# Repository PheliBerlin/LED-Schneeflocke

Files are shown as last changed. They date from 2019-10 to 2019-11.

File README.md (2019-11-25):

# LED-Schneeflocke

Eine leuchtende LED Schneeflocke für den Schreibtisch

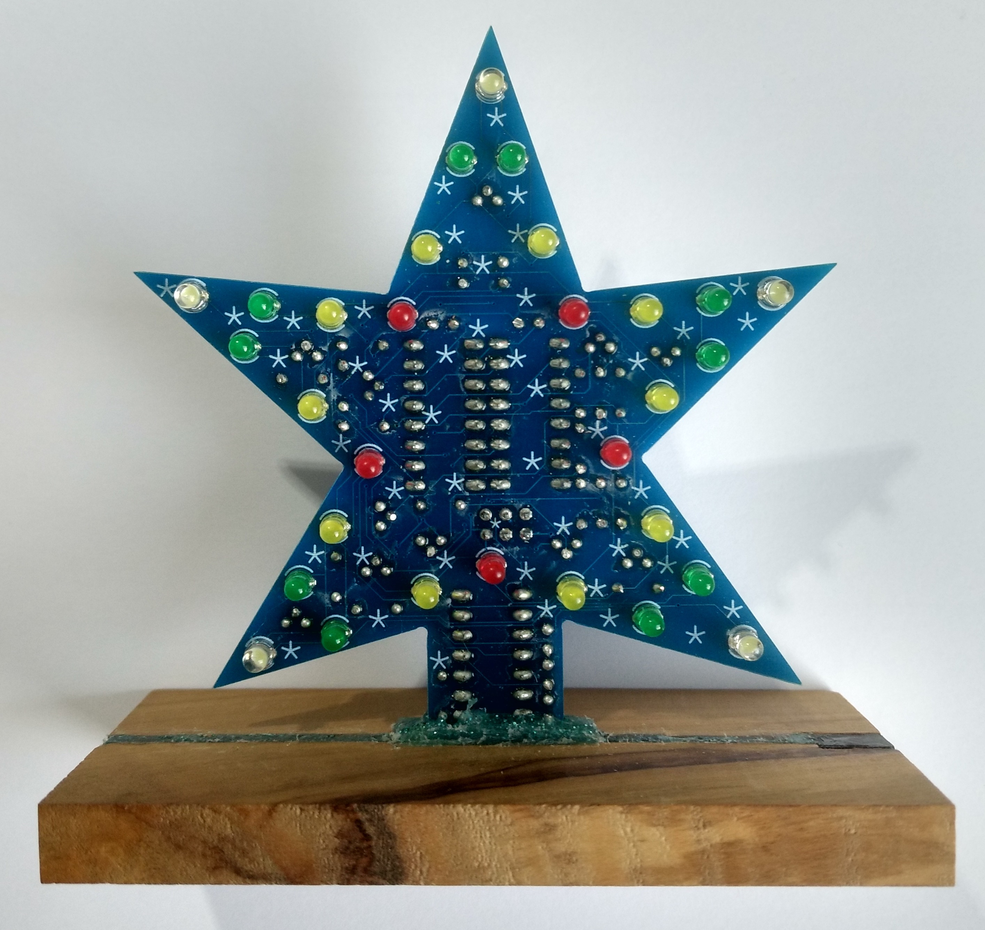
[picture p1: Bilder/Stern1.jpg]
Aufgebaut


Gesteuert wird alles mit einen ATtiny84, der mit zwei Shiftregistern die 30 LED schaltet.

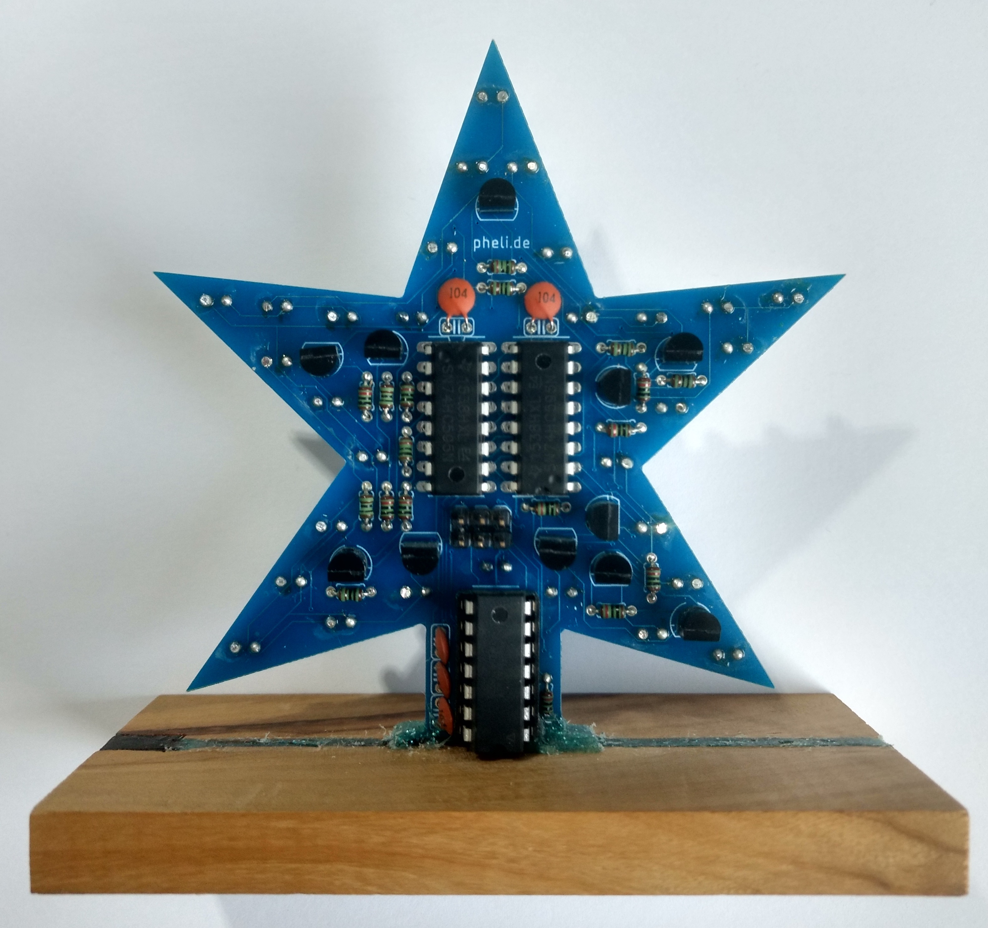
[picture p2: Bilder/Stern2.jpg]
ATtiny


Als Fuß habe ich ein Stück Holz vom Olivenbaum genommen.

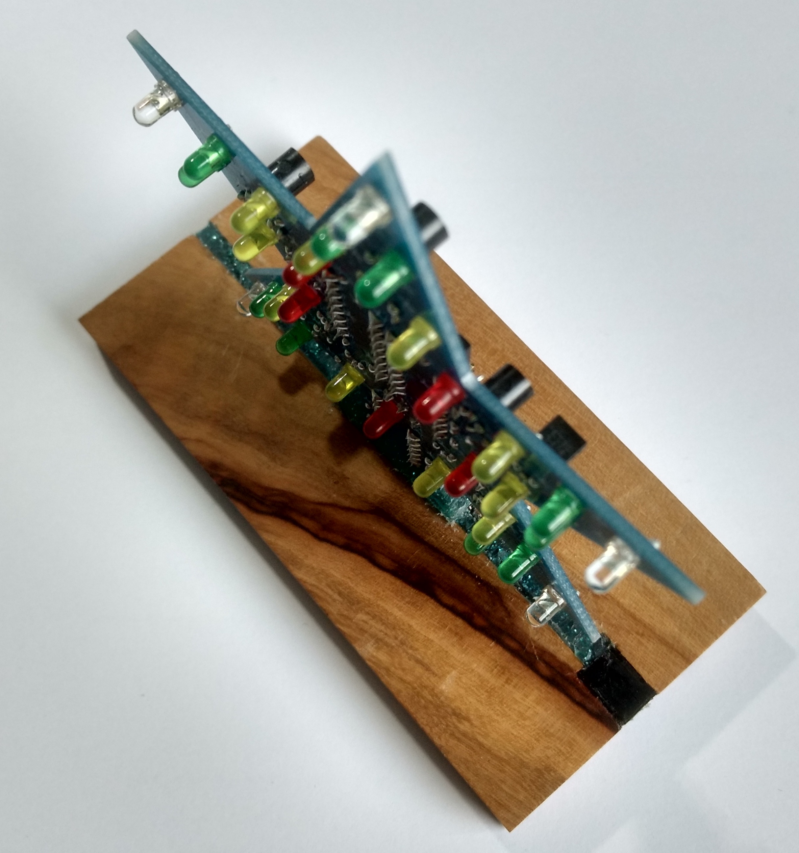
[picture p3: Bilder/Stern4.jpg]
Standfuß


Da es zum Anschluß an den USB- Anschluß gedacht war, sollte es auch nicht zu viel Strom ziehen. Obwohl ich auf keine Optimierungen im Stromverbrauch geachtet habe, ist der Stromverbrauch auch bei allen 30 leuchtenden LED nur gering.

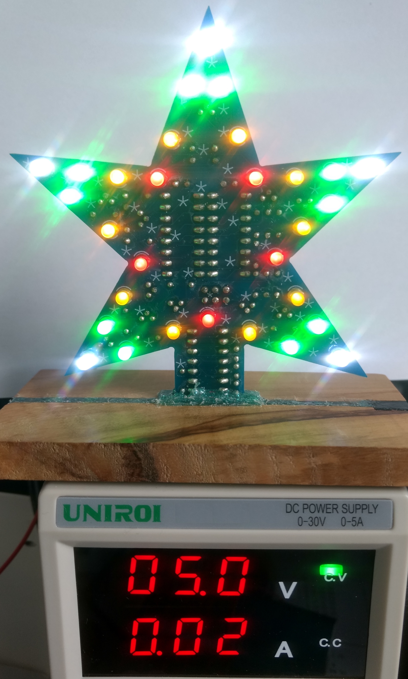
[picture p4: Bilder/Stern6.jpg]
Strom


Die Veröffentlichung erfolgt hier unter GNU General Public License Version 3.

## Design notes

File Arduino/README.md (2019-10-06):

xmasStern - Der Weihnachtsstern
==========

Installation
-------
Einfach den Ordner xmasStern in den Arduino library Ordner kopieren.

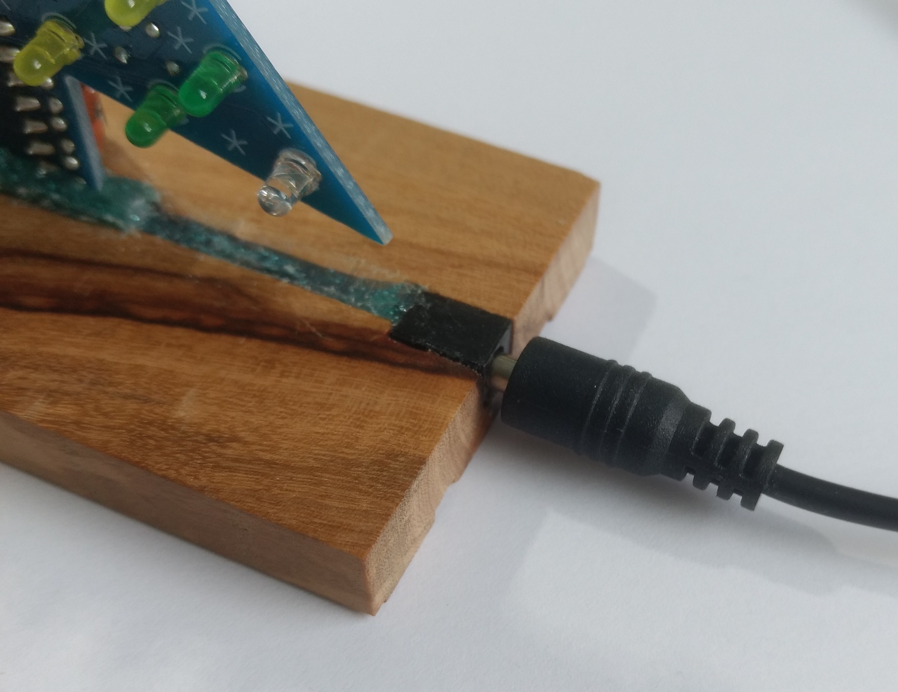
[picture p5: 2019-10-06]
Bilder/Stern5.jpg

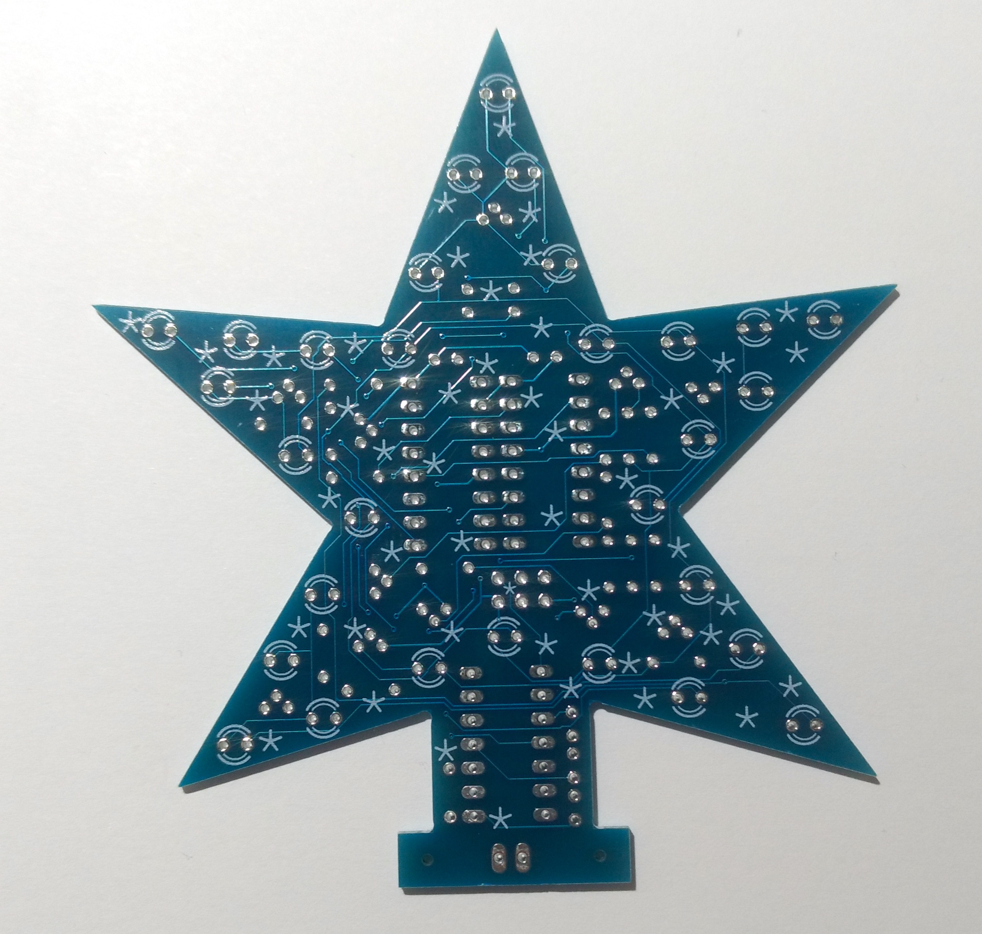
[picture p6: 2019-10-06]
Bilder/Stern3.jpg

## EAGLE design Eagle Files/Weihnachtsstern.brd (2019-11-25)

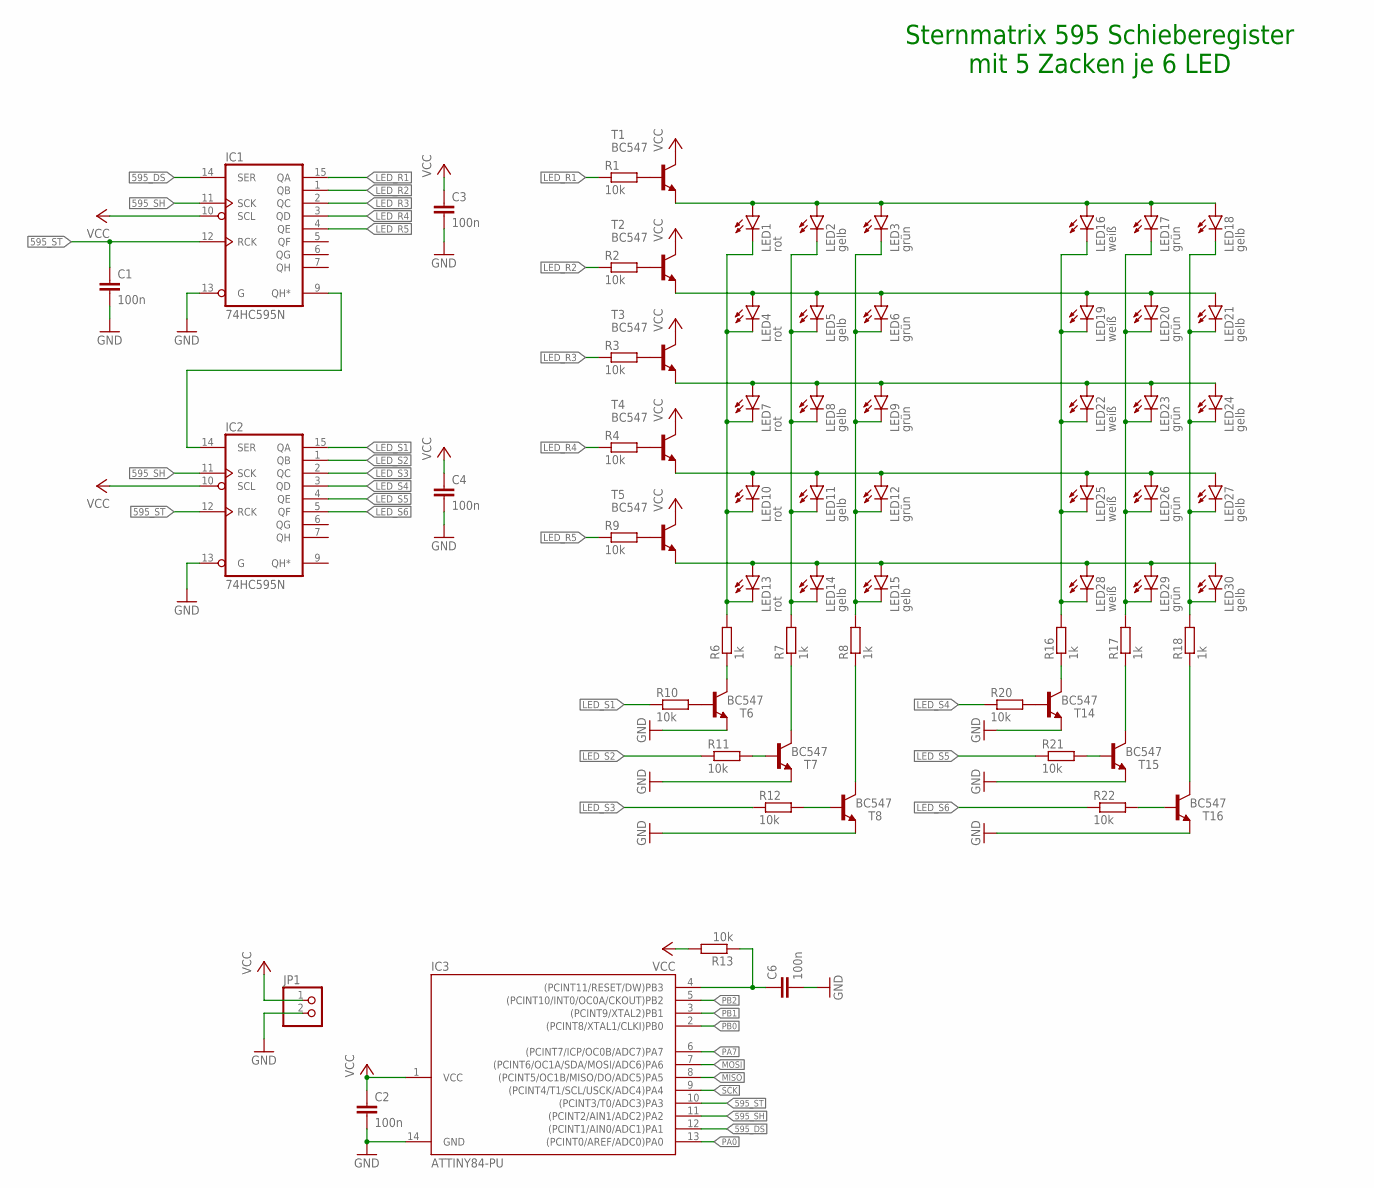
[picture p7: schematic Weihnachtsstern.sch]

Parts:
C1, C2, C3, C4, C6: 100n; C025-024X044
IC1, IC2: 74HC595N; DIL16
IC3: ATTINY84-PU; DIL14
JP1: PINHD-1X2; 1X02
LED1, LED4, LED7, LED10, LED13: rot; LED3MM
LED2, LED5, LED8, LED11, LED14, LED15, LED18, LED21, LED24, LED27, LED30: gelb; LED3MM
LED3, LED6, LED9, LED12, LED17, LED20, LED23, LED26, LED29: grün; LED3MM
LED16, LED19, LED22, LED25, LED28: weiß; LED3MM
R1, R2, R3, R4, R9, R10, R11, R12, R13, R20, R21, R22: 10k; 0204/5
R6, R7, R8, R16, R17, R18: 1k; 0204/5
T1, T2, T3, T4, T5, T6, T7, T8, T14, T15, T16: BC547; TO92

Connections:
595_DS: IC1.14 (SER), IC3.12 ((PCINT1/AIN0/ADC1)PA1)
595_SH: IC1.11 (SCK), IC2.11 (SCK), IC3.11 ((PCINT2/AIN1/ADC2)PA2)
595_ST: C1.1, IC1.12 (RCK), IC2.12 (RCK), IC3.10 ((PCINT3/T0/ADC3)PA3)
GND: C1.2, C2.2, C3.2, C4.2, C6.2, IC1.8 (GND), IC1.13 (G), IC2.8 (GND), IC2.13 (G), IC3.14 (GND), JP1.2, T6.1 (E), T7.1 (E), T8.1 (E), T14.1 (E), T15.1 (E), T16.1 (E)
LED_R1: IC1.15 (QA), R1.1
LED_R2: IC1.1 (QB), R2.1
LED_R3: IC1.2 (QC), R3.1
LED_R4: IC1.3 (QD), R4.1
LED_R5: IC1.4 (QE), R9.1
LED_S1: IC2.15 (QA), R10.1
LED_S2: IC2.1 (QB), R11.1
LED_S3: IC2.2 (QC), R12.1
LED_S4: IC2.3 (QD), R20.1
LED_S5: IC2.4 (QE), R21.1
LED_S6: IC2.5 (QF), R22.1
MISO: IC3.8 ((PCINT5/OC1B/MISO/DO/ADC5)PA5)
MOSI: IC3.7 ((PCINT6/OC1A/SDA/MOSI/ADC6)PA6)
unnamed: R7.1, T7.3 (C)
unnamed: R1.2, T1.2 (B)
unnamed: R2.2, T2.2 (B)
unnamed: R3.2, T3.2 (B)
unnamed: R4.2, T4.2 (B)
unnamed: R6.1, T6.3 (C)
unnamed: R8.1, T8.3 (C)
unnamed: R9.2, T5.2 (B)
unnamed: R10.2, T6.2 (B)
unnamed: R11.2, T7.2 (B)
unnamed: R12.2, T8.2 (B)
unnamed: R16.1, T14.3 (C)
unnamed: R18.1, T16.3 (C)
unnamed: R20.2, T14.2 (B)
unnamed: R21.2, T15.2 (B)
unnamed: R22.2, T16.2 (B)
unnamed: R17.1, T15.3 (C)
PA0: IC3.13 ((PCINT0/AREF/ADC0)PA0)
PA7: IC3.6 ((PCINT7/ICP/OC0B/ADC7)PA7)
PB0: IC3.2 ((PCINT8/XTAL1/CLKI)PB0)
PB1: IC3.3 ((PCINT9/XTAL2)PB1)
PB2: IC3.5 ((PCINT10/INT0/OC0A/CKOUT)PB2)
R1: LED1.A, LED2.A, LED3.A, LED16.A, LED17.A, LED18.A, T1.1 (E)
R2: LED4.A, LED5.A, LED6.A, LED19.A, LED20.A, LED21.A, T2.1 (E)
R3: LED7.A, LED8.A, LED9.A, LED22.A, LED23.A, LED24.A, T3.1 (E)
R4: LED10.A, LED11.A, LED12.A, LED25.A, LED26.A, LED27.A, T4.1 (E)
R5: LED13.A, LED14.A, LED15.A, LED28.A, LED29.A, LED30.A, T5.1 (E)
RESET: C6.1, IC3.4 ((PCINT11/RESET/DW)PB3), R13.1
S1: LED1.K (C), LED4.K (C), LED7.K (C), LED10.K (C), LED13.K (C), R6.2
S2: LED2.K (C), LED5.K (C), LED8.K (C), LED11.K (C), LED14.K (C), R7.2
S3: LED3.K (C), LED6.K (C), LED9.K (C), LED12.K (C), LED15.K (C), R8.2
S4: LED16.K (C), LED19.K (C), LED22.K (C), LED25.K (C), LED28.K (C), R16.2
S5: LED17.K (C), LED20.K (C), LED23.K (C), LED26.K (C), LED29.K (C), R17.2
S6: LED18.K (C), LED21.K (C), LED24.K (C), LED27.K (C), LED30.K (C), R18.2
SCK: IC3.9 ((PCINT4/T1/SCL/USCK/ADC4)PA4)
UELAUF: IC1.9 (QH*), IC2.14 (SER)
VCC: C2.1, C3.1, C4.1, IC1.10 (SCL), IC1.16 (VCC), IC2.10 (SCL), IC2.16 (VCC), IC3.1 (VCC), JP1.1, R13.2, T1.3 (C), T2.3 (C), T3.3 (C), T4.3 (C), T5.3 (C)

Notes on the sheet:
Sternmatrix 595 Schieberegister mit 5 Zacken je 6 LED

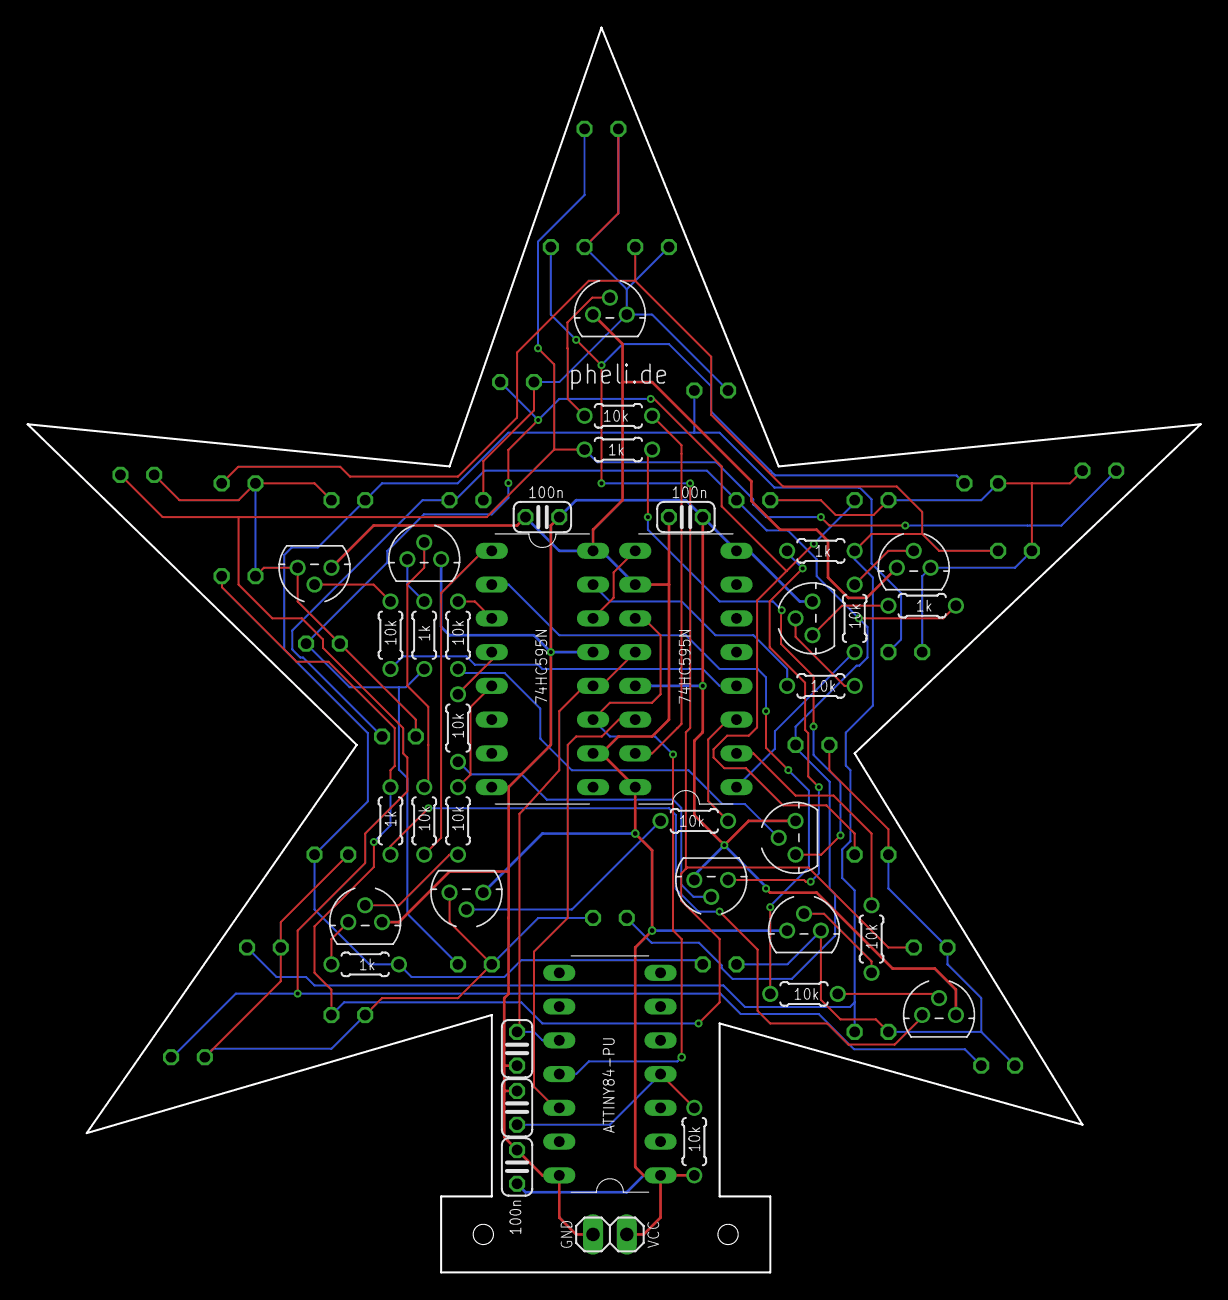
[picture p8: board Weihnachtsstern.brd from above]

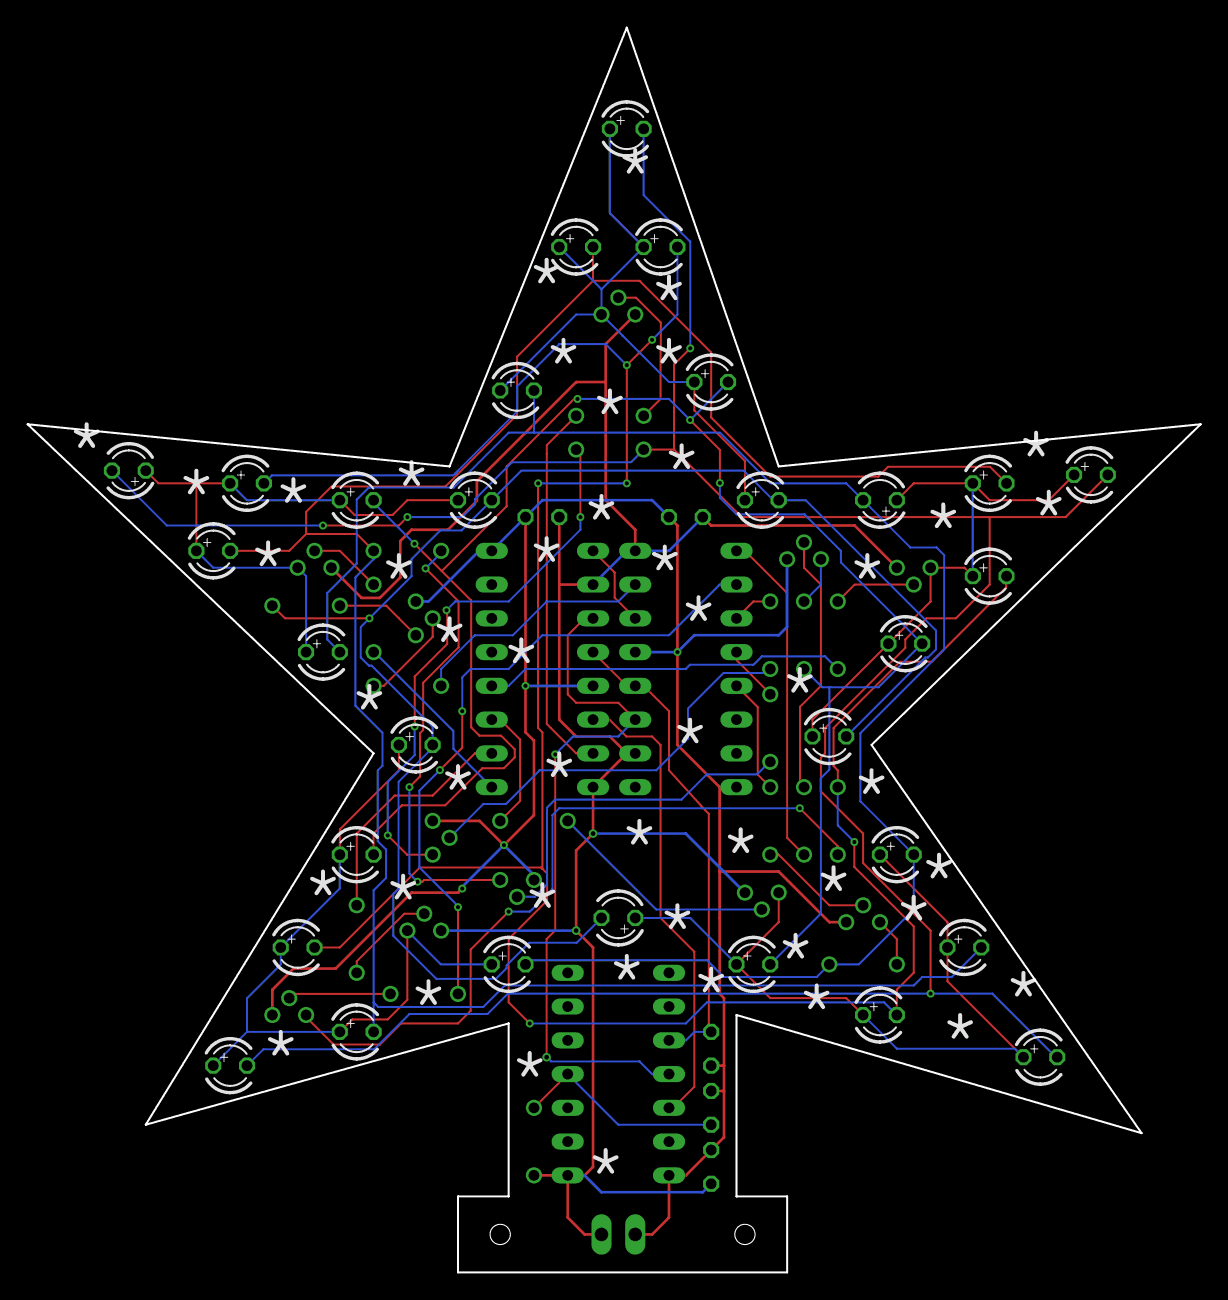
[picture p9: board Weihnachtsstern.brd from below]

Board: 2 copper layers, 88.3 x 93.7 mm, 68 parts (30 on the bottom side), 46 nets.

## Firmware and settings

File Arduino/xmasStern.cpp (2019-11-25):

#include "Arduino.h"

#include "xmasStern.h"


xmasStern::xmasStern(byte latchPin, byte clockPin, byte dataPin) {
  pinMode(latchPin, OUTPUT);
  pinMode(clockPin, OUTPUT);
  pinMode(dataPin, OUTPUT);

  _latchPin = latchPin;
  _clockPin = clockPin;
  _dataPin = dataPin;

  // Die einzelnen Pins am Stern deklarieren
  // Jede Zeile eine Spitze
  // rot, gelb, grün, weiß, grün, geld (Spitze im Uhreigersinn)
  byte zaehler = 0;
  for (byte i = 0; i < 5; i++) {
    for (byte n = 0; n < 6; n++) {
      _leds[zaehler][0] = 128 >> i;
      _leds[zaehler][1] = 128 >> n;
      zaehler += 1;
    }
  }
  aus();
}

void xmasStern::sternDelay(unsigned long zeit)
{
	unsigned long time = millis();
	unsigned long diff;
	
	do
	{
		diff = millis() - time;
	} while ( diff < zeit );
}

void xmasStern::shiftOut_neu(byte wert) {
  byte i;

  for (i = 0; i < 8; i++) {
    //digitalWrite(dataPin, !!(val & (1 << i)));
    if ((!!(wert & (1 << i))) == HIGH)
      PORTA |= (1 << _dataPin);
    else PORTA &= ~(1 << _dataPin);

    //digitalWrite(clockPin, HIGH);
    PORTA |= (1 << _clockPin);

    //digitalWrite(clockPin, LOW);
    PORTA &= ~(1 << _clockPin);
  }
}

void xmasStern::senden(byte wert1, byte wert2) {
  // latchPin auf LOW damit
  // die LED beim Senden nicht blinken

  //digitalWrite(latchPin, LOW);
  PORTA &= ~(1 << _latchPin);

  // Erst das zweite Register, dann das erste
  shiftOut_neu(wert2);
  shiftOut_neu(wert1);

  //digitalWrite(latchPin, HIGH);
  PORTA |= (1 << _latchPin);
}

// Nur die einzelnen Farben ansteuren
void xmasStern::weiss() {
  senden(0b11111000, 0b00010000);
}

void xmasStern::rot() {
  senden(0b11111000, 0b10000000);
}

void xmasStern::gruen() {
  senden(0b11111000, 0b00101000);
}

void xmasStern::gelb() {
  senden(0b11111000, 0b01000100);
}

// Alle LED ausschalten
void xmasStern::aus() {
  senden(0, 0);
}

// Alle LED ausschalten
void xmasStern::an() {
  senden(255, 255);
}

// Effekte
void xmasStern::umlaufLinks(int speed) {
	for ( byte i = 0; i< 30; i++ )
	{
		eineLED(i);
		sternDelay(speed);
	}
}
void xmasStern::umlaufrechts(int speed) {
  for ( byte i = 30; i > 0; i-- )
  {
	  eineLED(i);
	  sternDelay(speed);
	}
}
void xmasStern::sparkle(int speed) {// speed = 250-300 sieht gut aus 
  weiss();
  sternDelay(speed);
  gruen();
  sternDelay(speed);
  gelb();
  sternDelay(speed);
  rot();
  sternDelay(speed);
  gelb();
  sternDelay(speed);
  gruen();
  sternDelay(speed);
}
void xmasStern::viererrunde(int speed) // speed = 30-40 sieht gut aus
{
  byte led1, led2, led3, led4;

  for (led1 = 0; led1 < 30; led1++) {
    led2 = led1 + 1;
    led2 = (led2 == 30 ? 0 : led2);
    led3 = led1 + 2;
    led3 = (led3 == 30 ? 0 : led3);
    led3 = (led3 == 31 ? 1 : led3);
    led4 = led1 + 3;
    led4 = (led4 == 30 ? 0 : led4);
    led4 = (led4 == 31 ? 1 : led4);
    led4 = (led4 == 32 ? 2 : led4);

    for (int i = 0; i < speed; i++) {
      senden(_leds[led1][0], _leds[led1][1]);
      senden(_leds[led2][0], _leds[led2][1]);
      senden(_leds[led3][0], _leds[led3][1]);
      senden(_leds[led4][0], _leds[led4][1]);
    }
  }
}
void xmasStern::gelberring(int runden, int speed) {
  for (byte n = 0; n < runden; n++) {
    senden(0b11111000, 0b01000000);
    sternDelay(speed);
    senden(0b11111000, 0b00000100);
    sternDelay(speed);
  }
}
void xmasStern::gruenerring(int runden, int speed) {
  for (byte n = 0; n < runden; n++) {
    senden(0b11111000, 0b00001000);
    sternDelay(speed);
    senden(0b11111000, 0b00100000);
    sternDelay(speed);
  }
}
void xmasStern::ring(int runden, int speed) {
  for (byte n = 0; n < runden; n++) {
    senden(0b11111000, 0b11010000);
    sternDelay(speed);
    senden(0b11111000, 0b10100100);
    sternDelay(speed);
    senden(0b11111000, 0b01011000);
    sternDelay(speed);
    senden(0b11111000, 0b00101100);
    sternDelay(speed);
  }
}
void xmasStern::spitze(byte spitze, int dauer) {
  if (spitze > 4) return;

  for (int i = 0; i < dauer; i++) {
    senden(128 >> spitze, 0b01111100);
    sternDelay(2);
    rot();
    sternDelay(4);
  }
}
void xmasStern::eineLED(byte nummer) {
  if (nummer > 29) return;
  senden(_leds[nummer][0], _leds[nummer][1]);
}
void xmasStern::eineLEDaus(byte nummer) {
  if (nummer > 29) return;
  for (byte i = 0; i < 30; i++) {
    if (i == nummer) {
      aus();
    } else {
      eineLED(i);
    }
  }
}
void xmasStern::umlaufAlleRechts(int spped) {
  for (byte i = 30; i > 0; i--) {
    for (byte n = 0; n < 20; n++) {
      eineLEDaus(i - 1);
    }
  }
}
void xmasStern::umlaufAlleLinks(int speed) {
  for (byte i = 0; i < 29; i++) {
    for (byte n = 0; n < 20; n++) {
      eineLEDaus(i);
    }
  }
}
void xmasStern::feuerWerk(int speed) {
	int i = speed * 2;
	
	rot();
  sternDelay(i);
  gelb();
  sternDelay(i);
  gruen();
  sternDelay(i);
  an();
	sternDelay(i);
  weiss();
  sternDelay(speed);
  aus();
  sternDelay(speed);
  weiss();
  sternDelay(speed);
  aus();
  sternDelay(speed);
  weiss();
  sternDelay(speed);
  aus();
  sternDelay(speed);
	weiss();
  sternDelay(speed);
  aus();
  sternDelay(speed);
}
void xmasStern::tickTack(byte spitze1, byte spitze2, byte speed) {
	spitze(spitze1, speed);
	spitze(spitze2, speed);
	spitze(spitze1, speed);
	spitze(spitze2, speed);
}
	
	
	
	
	
	
	
	
	
	
	

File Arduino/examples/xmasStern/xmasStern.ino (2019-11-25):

/*
    Mein kleiner Weihnachtsstern für den Schreibtisch
    www.pheli.de

    Für die Steuerung des Sternes wird ein ATtiny84 genommen, der über die Arduino Umgebung programmiert wird.
    Als Frequenz habe ich die internen 8MHz des ATtiny84 genommen.
*/


#include <xmasStern.h>

/*  Pinbelegung für den Weihnachtsstern am 74HC595
      ST_CP  ->  3
      SH_CP  ->  2
      DS     ->  1
*/

xmasStern stern(3, 2, 1);


void setup() {
  // Nichts zu tun
}

void loop() {

  stern.tickTack(2, 3, 70);

  stern.spitze(4, 70);
  stern.spitze(0, 70);
  stern.spitze(1, 70);
  stern.spitze(2, 70);
  stern.spitze(3, 70);

  stern.an();

  stern.sternDelay(600);

  stern.feuerWerk(150);

  stern.sparkle(250);
  stern.sparkle(250);

  stern.umlaufLinks(80);
  stern.viererrunde(80);

}

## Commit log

2019-10-06 Gerber Dateien für die Platine
    [Weihnachtsstern.GBL, Weihnachtsstern.GBO, Weihnachtsstern.GBP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]
2019-11-25 Gerber gelöscht
    [Weihnachtsstern.GBL, Weihnachtsstern.GBO, Weihnachtsstern.GBP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]
2019-11-25 Eagle Files zugefügt
    [Weihnachtsstern.brd, Weihnachtsstern.sch]
